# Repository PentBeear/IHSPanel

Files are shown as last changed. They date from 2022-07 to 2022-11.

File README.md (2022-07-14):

# **IHSPanel**
   \
Run tasks and control your smart home from a touch screen interface.

This is a hardware project for a touch screen controller based on an ESP32 Microcontroller.
As this is a hardware only project, firmware for this panel will be from other sources, the preferred one being [openHASP.](https://github.com/HASwitchPlate/openHASP)

## Showcase

## Getting Started (Not released)
The documentation contains information, explanations, and frequently asked questions.\
For more help, please join the ______ on Discord

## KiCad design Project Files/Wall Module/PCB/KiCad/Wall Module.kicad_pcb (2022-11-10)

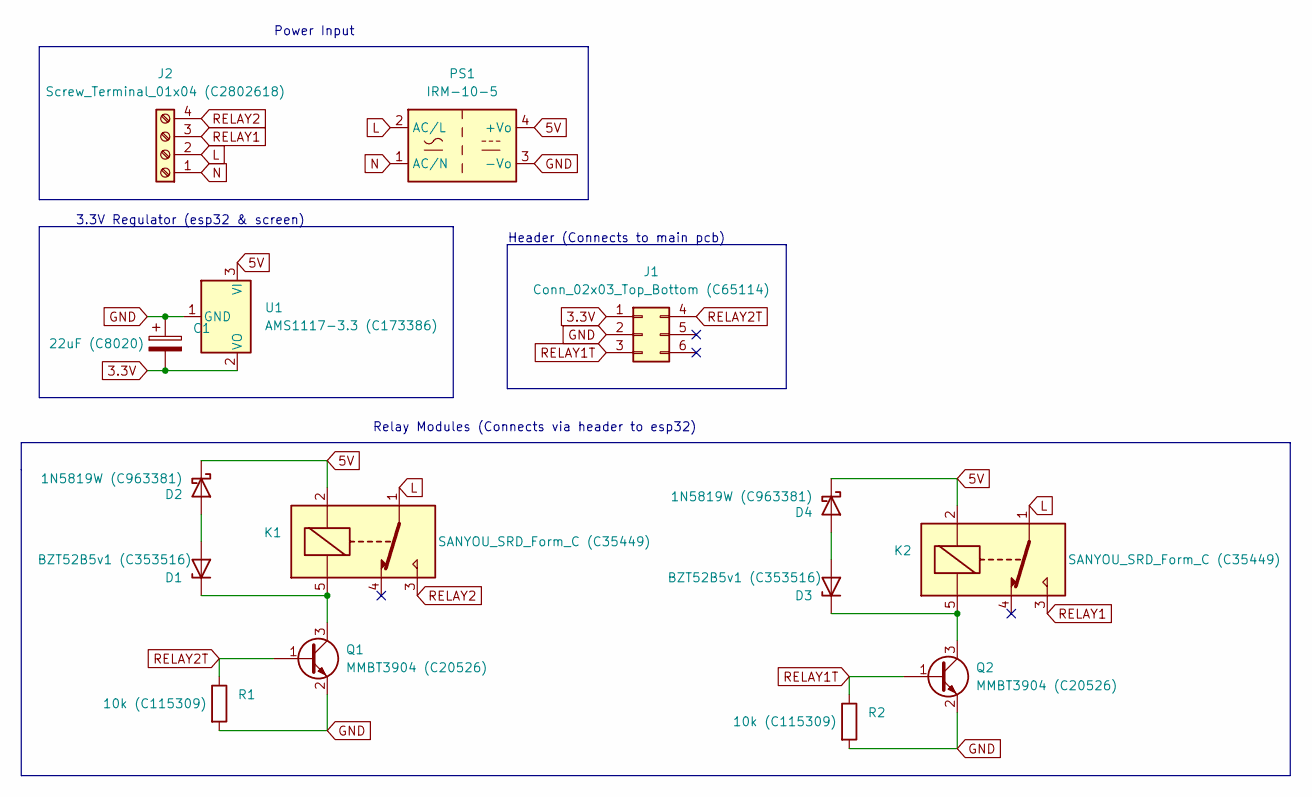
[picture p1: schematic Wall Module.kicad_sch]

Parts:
C1: 22uF (C8020); CP_EIA-3528-21_Kemet-B
D1, D3: BZT52B5v1 (C353516); D_SOD-123
D2, D4: 1N5819W (C963381); D_SOD-123
J1: Conn_02x03_Top_Bottom (C65114); PinHeader_2x03_P2.54mm_Vertical
J2: Screw_Terminal_01x04 (C2802618); TerminalBlock_Phoenix_MKDS-1,5-4_1x04_P5.00mm_Horizontal
K1, K2: SANYOU_SRD_Form_C (C35449); Relay_SPDT_SANYOU_SRD_Series_Form_C
PS1: IRM-10-5; Converter_ACDC_MeanWell_IRM-10-xx_THT
Q1, Q2: MMBT3904 (C20526); SOT-23
R1, R2: 10k (C115309); R_0805_2012Metric
U1: AMS1117-3.3 (C173386); SOT-223-3_TabPin2

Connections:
3.3V: C1.2, J1.1, U1.2 (VO)
5V: D2.1 (K), D4.1 (K), K1.2, K2.2, PS1.4 (+Vo), U1.3 (VI)
GND: C1.1, J1.2, PS1.3 (-Vo), Q1.2 (E), Q2.2 (E), R1.2, R2.2, U1.1 (GND)
L: J2.2, K1.1, K2.1, PS1.2 (AC/L)
N: J2.1, PS1.1 (AC/N)
unnamed: D1.1 (K), K1.5, Q1.3 (C)
unnamed: D1.2 (A), D2.2 (A)
unnamed: D3.1 (K), K2.5, Q2.3 (C)
unnamed: D3.2 (A), D4.2 (A)
RELAY1: J2.3, K2.3
RELAY1T: J1.3, Q2.1 (B), R2.1
RELAY2: J2.4, K1.3
RELAY2T: J1.4, Q1.1 (B), R1.1

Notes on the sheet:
Power Input
Header (Connects to main pcb)
Relay Modules (Connects via header to esp32)
3.3V Regulator (esp32 & screen)

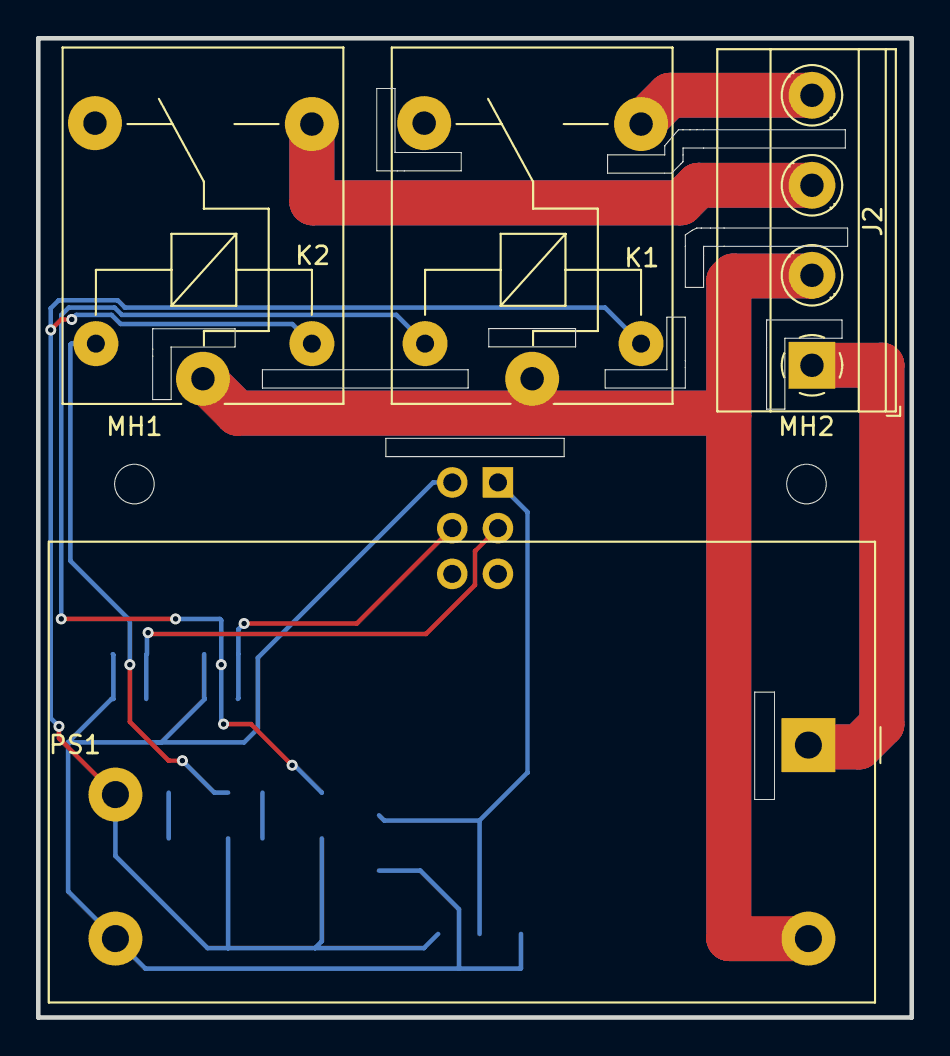
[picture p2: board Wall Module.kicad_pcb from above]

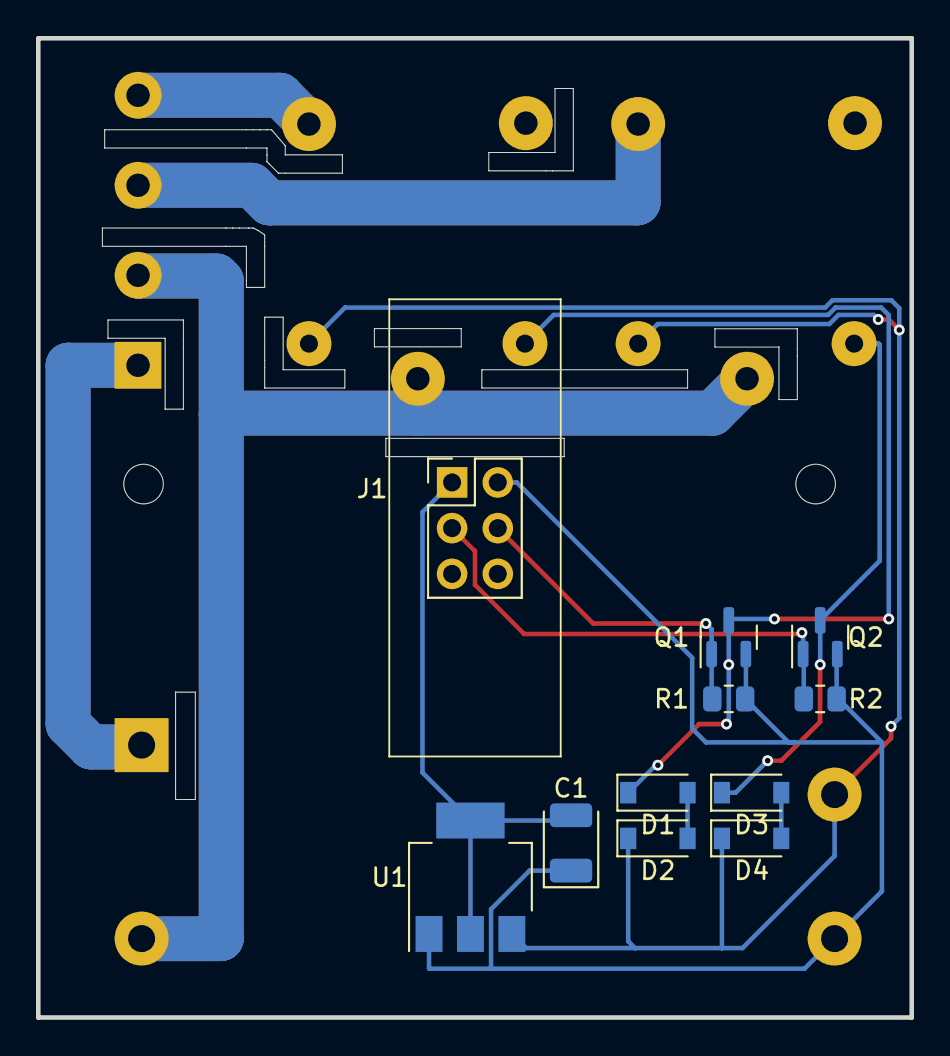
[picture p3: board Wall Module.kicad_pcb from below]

Board: 2 copper layers, 48.5 x 54.4 mm, 17 parts (11 on the bottom side), 13 nets.

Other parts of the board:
MH1, MH2: MountingHole_2.2mm_M2

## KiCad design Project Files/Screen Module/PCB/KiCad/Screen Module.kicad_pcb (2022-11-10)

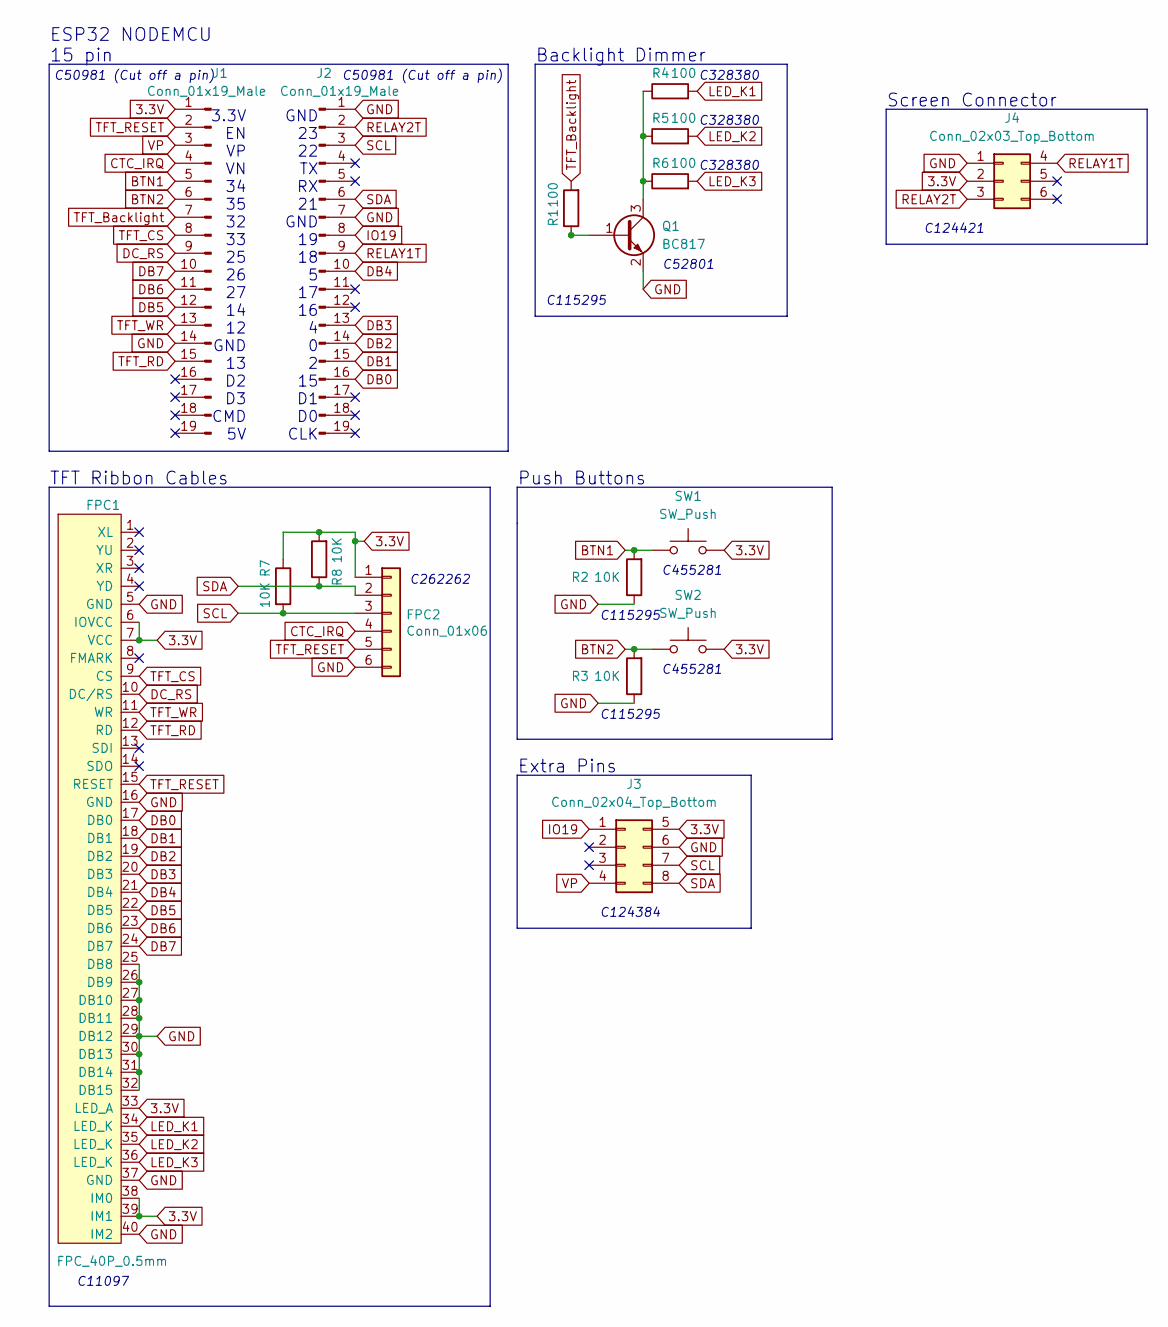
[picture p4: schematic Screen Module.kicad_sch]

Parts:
FPC1: FPC_40P_0.5mm; Hirose_FH12-40S-0.5SH_1x40-1MP_P0.50mm_Horizontal
FPC2: Conn_01x06; Hirose_FH12-6S-0.5SH_1x06-1MP_P0.50mm_Horizontal
J1, J2: Conn_01x19_Male; PinHeader_1x19_P2.54mm_Vertical
J3: Conn_02x04_Top_Bottom; PinHeader_2x04_P2.54mm_Vertical
J4: Conn_02x03_Top_Bottom; PinSocket_2x03_P2.54mm_Vertical
Q1: BC817; SOT-23
R1, R4, R5, R6: 100; R_0805_2012Metric
R2, R3, R7, R8: 10K; R_0805_2012Metric
SW1, SW2: SW_Push; TS-1088R-02526

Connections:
3.3V: FPC1.6 (IOVCC), FPC1.7 (VCC), FPC1.33 (LED_A), FPC1.38 (IM0), FPC1.39 (IM1), FPC2.1, J1.1, J3.5, J4.2, R7.1, R8.2, SW1.2, SW2.2
BTN1: J1.5, R2.2, SW1.1
BTN2: J1.6, R3.2, SW2.1
CTC_IRQ: FPC2.4, J1.4
DB0: FPC1.17 (DB0), J2.16
DB1: FPC1.18 (DB1), J2.15
DB2: FPC1.19 (DB2), J2.14
DB3: FPC1.20 (DB3), J2.13
DB4: FPC1.21 (DB4), J2.10
DB5: FPC1.22 (DB5), J1.12
DB6: FPC1.23 (DB6), J1.11
DB7: FPC1.24 (DB7), J1.10
DC_RS: FPC1.10 (DC/RS), J1.9
GND: FPC1.5 (GND), FPC1.16 (GND), FPC1.25 (DB8), FPC1.26 (DB9), FPC1.27 (DB10), FPC1.28 (DB11), FPC1.29 (DB12), FPC1.30 (DB13), FPC1.31 (DB14), FPC1.32 (DB15), FPC1.37 (GND), FPC1.40 (IM2), FPC2.6, J1.14, J2.1, J2.7, J3.6, J4.1, Q1.2 (E), R2.1, R3.1
IO19: J2.8, J3.1
LED_K1: FPC1.34 (LED_K), R4.2
LED_K2: FPC1.35 (LED_K), R5.2
LED_K3: FPC1.36 (LED_K), R6.2
unnamed: Q1.1 (B), R1.1
unnamed: Q1.3 (C), R4.1, R5.1, R6.1
RELAY1T: J2.9, J4.4
RELAY2T: J2.2, J4.3
SCL: FPC2.3, J2.3, J3.7, R7.2
SDA: FPC2.2, J2.6, J3.8, R8.1
TFT_Backlight: J1.7, R1.2
TFT_CS: FPC1.9 (CS), J1.8
TFT_RD: FPC1.12 (RD), J1.15
TFT_RESET: FPC1.15 (RESET), FPC2.5, J1.2
TFT_WR: FPC1.11 (WR), J1.13
VP: J1.3, J3.4

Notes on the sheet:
C115295
C455281
TFT Ribbon Cables
3.3V EN VP VN 34 35 32 33 25 26 27 14 12 GND 13 D2 D3 CMD 5V
C52801
C50981 (Cut off a pin)
Backlight Dimmer
C124384
Push Buttons
Extra Pins
C328380
GND 23 22 TX RX 21 GND 19 18 5 17 16 4 0 2 15 D1 D0 CLK
C11097
C262262
C124421
ESP32 NODEMCU 15 pin
Screen Connector

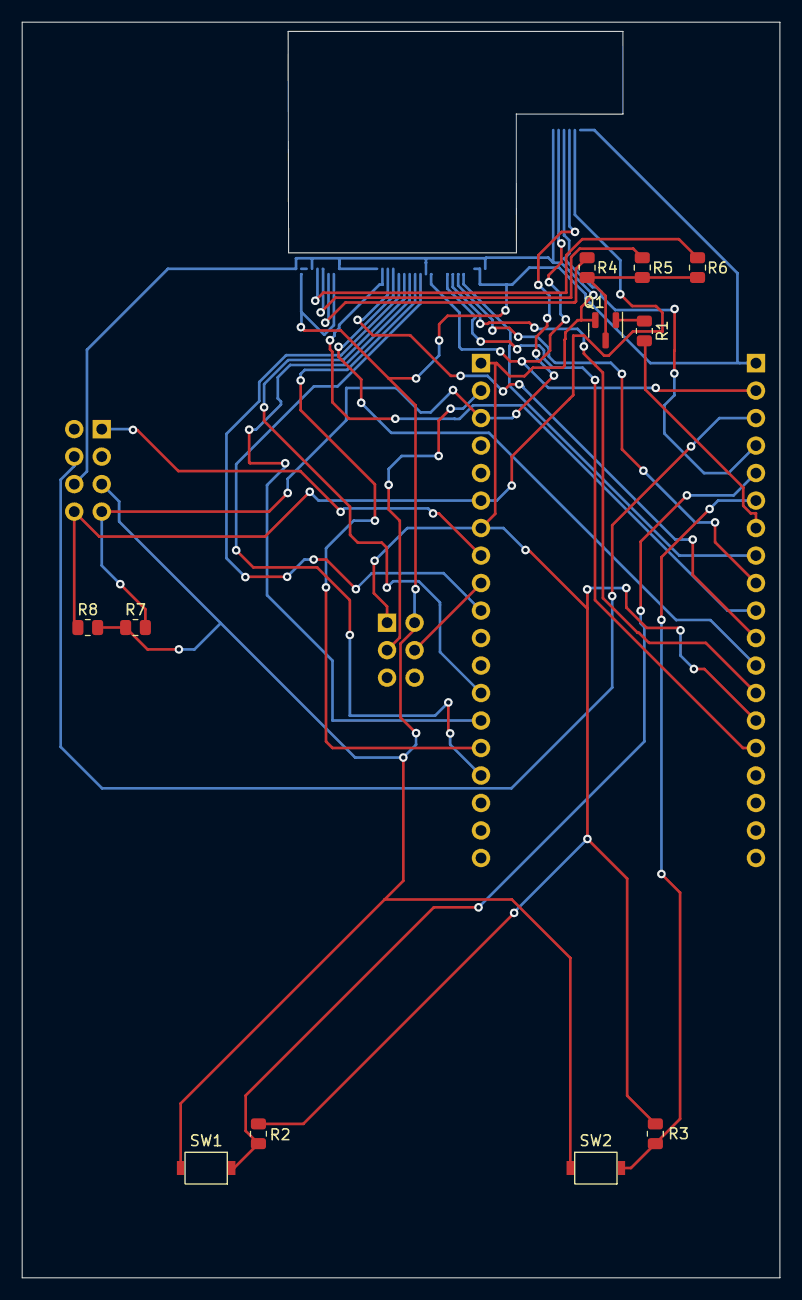
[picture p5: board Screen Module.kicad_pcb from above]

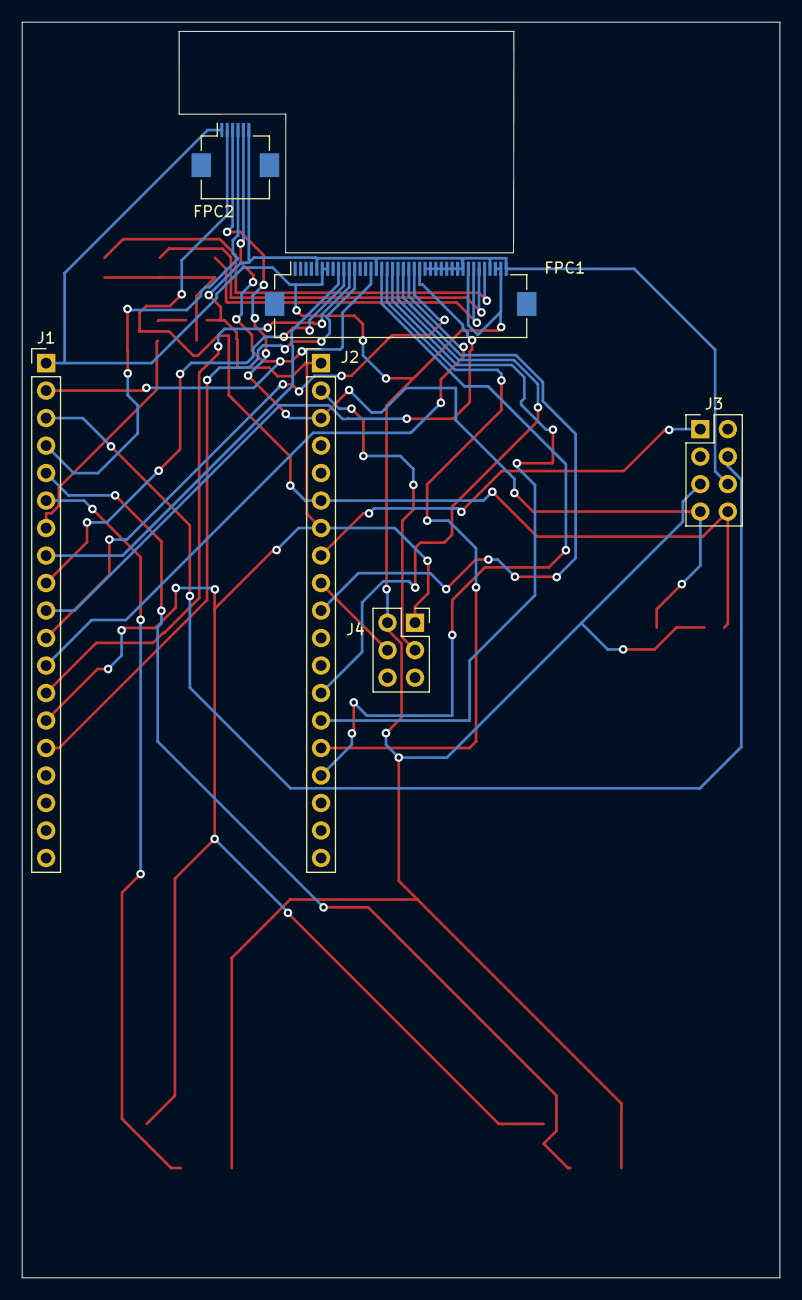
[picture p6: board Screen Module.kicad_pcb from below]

Board: 2 copper layers, 70.0 x 116.0 mm, 17 parts (6 on the bottom side), 30 nets.

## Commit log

2022-07-14 Initial commit to add current project files.
2022-07-16 Changed from EasyEDA to KiCad
    [Wall Module.kicad_pcb, Wall Module.kicad_sch]
2022-07-26 Made screen module pcb.
    [Screen Module.kicad_pcb, Screen Module.kicad_sch, Wall Module.kicad_pcb]
2022-11-10 Updated PCB to fix several issues Wall Module: Fixed relay flyback diodes pointing in the wrong direction.
    Screen PCB:
    Fixed display LED resistors to be a more suitable value.
    [Screen Module.kicad_pcb, Screen Module.kicad_sch, Wall Module.kicad_pcb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]
